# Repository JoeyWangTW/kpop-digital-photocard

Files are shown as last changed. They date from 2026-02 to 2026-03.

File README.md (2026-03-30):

# K-Pop Digital Photocard

A handheld device that plays K-pop YouTube Shorts as looping video "photocards" on a small display, powered by an ESP32-S3 with a 2.8" IPS screen.

<p align="center">
  Digital photocard playing video
  Back of 3D-printed case
  CO2 sensor mode
</p>

## Project Structure

```
kpop-digital-photocard/
├── firmware/          ESP32-S3 video player firmware (Arduino)
├── collection-app/    Streamlit app to browse, download & convert YouTube Shorts
├── case/              3D-printable enclosure (STL files)
└── docs/              Wiring diagrams, photos, BOM
```

## Hardware

### Parts List

| Part | Notes |
|---|---|
| [ESP32-S3 2.8" IPS Display (Hosyond)](https://amzn.to/4brwvC6) | ESP32-S3 with 320x240 ILI9341, SD card slot, PSRAM. Cheaper options available on AliExpress/Alibaba |
| MicroSD card | Any size works, FAT32 formatted |
| [Lipo Battery 1000mAh](https://amzn.to/40Pq1Xz) | JST connector, 3.7V |
| M3x12mm screws | For case assembly |
| [M3 Threaded inserts (M3xH4)](https://amzn.to/4lifAp9) | Heat-set with soldering iron into the 3D-printed case |

### 3D-Printed Case

STL files are in the `case/` folder:
- `front.stl` — Front shell with display cutout
- `back.stl` — Back cover
- `button.stl` — Boot button cap

Install the M3 threaded inserts into the case using a soldering iron, then secure with M3x12mm screws.

## Getting Started

### 1. Set Up the Collection App

The collection app is a Streamlit web app that lets you browse YouTube Shorts, download them, and convert to MJPEG format for the device.

**Prerequisites:**
- Python 3.12+
- [uv](https://docs.astral.sh/uv/) (Python package manager)
- FFmpeg

```bash
cd collection-app

# Install dependencies
uv sync

# Install FFmpeg if you haven't already
# macOS
brew install ffmpeg
# Ubuntu/Debian
sudo apt install ffmpeg

# Run the app
uv run streamlit run app.py
```

The app opens in your browser at `http://localhost:8501`.

### 2. Add Channels & Fetch Videos

1. In the sidebar, enter a YouTube channel URL, @handle, or channel ID
2. Click **Fetch All** or **Fetch New Videos** to pull the latest Shorts
3. Thumbnails and metadata are cached locally in `data/shorts.db`

### 3. Select & Download Videos

1. Browse the video grid and check the ones you want
2. Use bulk select to grab multiple videos at once
3. New videos (not previously seen) are highlighted

### 4. Convert to MJPEG

1. Adjust conversion settings in the sidebar:

   | Parameter | Default | Description |
   |-----------|---------|-------------|
   | Width | 240 | Output video width in pixels |
   | Height | 320 | Output video height in pixels |
   | Quality | 5 | MJPEG quality (2-31, lower = better) |
   | FPS | 15 | Frame rate |
   | Brightness | 0.05 | Brightness adjustment (-0.5 to 0.5) |
   | Contrast | 1.1 | Contrast adjustment (0.5 to 2.0) |
   | Aspect Mode | fit | How to handle aspect ratio (fit/fill/stretch) |

2. Presets are available for **CYD 2.8"** (240x320) and **CYD 4"** (320x480)
3. Click **Download & Convert** to process all selected videos

### 5. Prepare the SD Card

1. Format a microSD card as **FAT32**
2. Create a folder called `mjpeg` at the root of the SD card
3. Click **Export** in the app to copy converted `.mjpeg` files to a target folder, or manually copy from `collection-app/output/` to the SD card's `/mjpeg/` folder
4. The firmware reads FPS from the filename (e.g. `video_15fps.mjpeg`), otherwise defaults to 15 FPS

### 6. Flash the Firmware

The video player firmware is based on [esp32-2432S028_video_player](https://github.com/thelastoutpostworkshop/esp32-2432S028_video_player) by The Last Outpost Workshop, adapted for the ESP32-S3.

1. Install [Arduino IDE](https://www.arduino.cc/en/software)
2. Add ESP32 board support: in **Settings > Additional Board Manager URLs**, add:
   ```
   https://raw.githubusercontent.com/espressif/arduino-esp32/gh-pages/package_esp32_index.json
   ```
3. Install **esp32** board package from Board Manager
4. Install required libraries via Library Manager:
   - **TFT_eSPI**
   - **TJpg_Decoder**
5. Copy `firmware/User_Setup.h` to your TFT_eSPI library folder (replacing the default), or update the pin definitions to match
6. Open `firmware/esp32s3_video_player.ino` in Arduino IDE
7. Select board: **ESP32S3 Dev Module**
8. Board settings:
   - Flash Size: **16MB**
   - PSRAM: **OPI PSRAM**
   - USB CDC On Boot: **Enabled** (for serial monitor)
   - Partition Scheme: **Huge APP**
9. Connect the board via USB and click **Upload**

### 7. Usage

- Insert the SD card and power on the device
- Videos in `/mjpeg/` loop automatically
- **Short press** the boot button to skip to the next video
- **Long press** (1.5s) the boot button to enter deep sleep
- **Press** the boot button again to wake from sleep

## License

MIT

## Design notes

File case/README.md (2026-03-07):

# Case

3D-printable enclosure for the K-Pop Digital Photocard device.

## Parts

- `front.stl` — Front shell with display cutout
- `back.stl` — Back cover
- `button.stl` — Boot button cap

## Assembly

1. Print all three parts
2. Heat-set four M3x4mm threaded inserts into the front part using a soldering iron
3. Place the ESP32-S3 board into the front shell and snap in the button cap
4. Connect the lipo battery to the board
5. Use double-sided tape to secure the battery to the inside of the back cover
6. Place the back cover on and fasten with four M3x12mm screws

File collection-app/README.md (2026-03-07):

# CYD Shorts Converter

Fetch YouTube Shorts from channels and convert them to MJPEG format optimized for the CYD (Cheap Yellow Display) ESP32 device.

## Features

- Add YouTube channels by URL, @handle, or channel ID
- Fetch and display Shorts with thumbnails
- Track new vs previously seen videos
- Select videos individually or in bulk
- Download and convert to MJPEG format
- Adjustable conversion parameters (resolution, quality, FPS, brightness, contrast)
- Export to SD card or target folder
- Remembers selections between sessions

## Requirements

- Python 3.12+
- [uv](https://docs.astral.sh/uv/)
- FFmpeg

## Installation

1. Clone or download this repository

2. Install dependencies:
```bash
uv sync
```

3. Install FFmpeg:
```bash
# macOS
brew install ffmpeg

# Ubuntu/Debian
sudo apt install ffmpeg

# Windows
choco install ffmpeg
```

## Usage

Start the application:

```bash
uv run streamlit run app.py
```

The app will open in your browser at `http://localhost:8501`.

### Workflow

1. **Add Channels**: Enter a YouTube channel URL or @handle in the sidebar
2. **Fetch Videos**: Click "Fetch All" or "Fetch New Videos" to get Shorts
3. **Select Videos**: Check the videos you want to convert
4. **Adjust Settings**: Configure resolution, quality, and other parameters
5. **Convert**: Click "Download & Convert" to process selected videos
6. **Export**: Click "Export" to copy converted files to your target folder

### Settings

| Parameter | Default | Description |
|---|---|---|
| Width | 240 | Output video width in pixels |
| Height | 320 | Output video height in pixels |
| Quality | 5 | MJPEG quality (2-31, lower = better) |
| FPS | 15 | Frame rate |
| Brightness | 0.05 | Brightness adjustment (-0.5 to 0.5) |
| Contrast | 1.1 | Contrast adjustment (0.5 to 2.0) |
| Aspect Mode | fit | How to handle aspect ratio (fit/fill/stretch) |

### Presets

- **CYD 2.8"**: 240x320, optimized for the 2.8" display
- **CYD 4"**: 320x480, optimized for the 4" display

## Project Structure

```
digital-photocard-collection/
├── app.py                  # Streamlit application
├── pyproject.toml          # Project config and dependencies
├── src/
│   ├── models/            # Data classes
│   ├── services/          # Business logic
│   ├── components/        # Streamlit UI components
│   └── utils/             # Utilities
├── data/
│   ├── shorts.db          # SQLite database
│   ├── thumbnails/        # Cached thumbnails
│   └── downloads/         # Temporary downloads
└── output/                # Converted MJPEG files
```

## CYD Device

The CYD (Cheap Yellow Display) is the ESP32-2432S028R board with:
- ESP32-WROOM-32 MCU
- 2.8" ILI9341 TFT display (240x320 pixels)
- SD card slot for video storage

Copy the exported `.mjpeg` files to an SD card and use with a compatible MJPEG player firmware.

## License

MIT

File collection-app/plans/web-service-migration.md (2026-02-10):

# CYD Shorts Converter - Web Service Migration

## Overview

Migrate the CYD Shorts Converter from a local Streamlit app to a public-facing web service. Two product models are considered: an **ephemeral downloader** (paste URL, convert, download) and an **account-based service** (saved collections, user profiles). The ephemeral model is the recommended starting point.

## Why Move Off Streamlit

The current Streamlit app works well as a local tool but has hard blockers for a public service:

| Requirement | Streamlit Support |
|---|---|
| Ad injection (AdSense, etc.) | No HTML control -- impossible |
| User authentication | No native support |
| SEO / discoverability | Single-page app, not crawlable |
| Custom branding / design | Very limited theming |
| Concurrent users at scale | Expensive (full Python process per session) |
| Background job processing | Blocks the user session |
| URL routing | Not supported |
| File downloads to browser | Limited (`st.download_button` only) |

## What We Keep

The existing service layer is cleanly decoupled from Streamlit and is fully reusable:

| File | What It Does | Reusable? |
|---|---|---|
| `src/services/conversion_service.py` | FFmpeg MJPEG pipeline | Yes -- no Streamlit dependency |
| `src/services/download_service.py` | yt-dlp video download | Yes -- no Streamlit dependency |
| `src/services/youtube_service.py` | Channel/video metadata fetching | Yes -- no Streamlit dependency |
| `src/models/` | Data classes (Video, Channel, Settings) | Yes -- plain Python dataclasses |
| `src/utils/ffmpeg_utils.py` | FFmpeg detection and helpers | Yes |
| `src/services/database.py` | SQLite persistence | Needs rework for multi-user |
| `src/components/` | Streamlit UI components | No -- replaced entirely |

## Product Model Decision

### Option A: Ephemeral Downloader (Recommended Start)

Users land on the site, paste a YouTube URL (or browse channels), pick conversion settings, and download the `.mjpeg` file. No account required. Monetize with ads.

**Pros:**
- Simplest to build and ship
- No auth, no user storage, no ongoing data responsibility
- Easy to monetize with display ads
- Low infrastructure cost (temp files auto-cleaned)
- Good for SEO ("youtube to mjpeg converter", "CYD video converter")

**Cons:**
- No user retention / return visits without new features
- Can't save collections or history
- Harder to build a community around

### Option B: Account-Based Service

Users create accounts, save channels, maintain collections, track conversion history.

**Pros:**
- User retention and repeat visits
- Can build community features (share collections, popular channels)
- Subscription potential (free tier with limits, paid for more)

**Cons:**
- Significantly more infrastructure (auth, user DB, file storage)
- Data responsibility (GDPR, user data management)
- Higher hosting costs (persistent storage per user)
- Longer time to ship

### Recommendation

**Start with Option A**, then layer on accounts (Option B) once there's traction. The backend architecture supports both -- adding auth and user-scoped storage later is straightforward.

---

## Technical Architecture

### Option A: Ephemeral Downloader

```
                    ┌─────────────────────────────────────┐
                    │         Frontend (Next.js)           │
                    │  ┌───────────────────────────────┐   │
                    │  │  Landing page (SEO-optimized) │   │
                    │  │  URL input + settings form    │   │
                    │  │  Progress polling UI           │   │
                    │  │  Download button               │   │
                    │  │  Ad placements (sidebar, top)  │   │
                    │  └───────────────────────────────┘   │
                    └──────────────┬──────────────────────┘
                                   │ REST API
                    ┌──────────────▼──────────────────────┐
                    │         Backend (FastAPI)            │
                    │  POST /api/convert                   │
                    │  GET  /api/status/{job_id}           │
                    │  GET  /api/download/{job_id}         │
                    │  GET  /api/presets                   │
                    └──────────────┬──────────────────────┘
                                   │ Task queue
                    ┌──────────────▼──────────────────────┐
                    │     Worker (Celery or arq)           │
                    │  ┌─────────────────────────────┐     │
                    │  │  download_service.py (reuse) │     │
                    │  │  conversion_service.py (reuse│)    │
                    │  └─────────────────────────────┘     │
                    │           │                │          │
                    │     yt-dlp download    FFmpeg convert │
                    └──────────────┬──────────────────────┘
                                   │
                    ┌──────────────▼──────────────────────┐
                    │         Storage                      │
                    │  Redis: job queue + status cache      │
                    │  /tmp/jobs/{job_id}/: temp files      │
                    │  Cron: cleanup files > 1 hour old     │
                    └──────────────────────────────────────┘
```

### Option B: Account-Based (future layer)

Adds on top of Option A:

```
                    ┌──────────────────────────────────────┐
                    │  Auth Provider (Clerk / Supabase)     │
                    └──────────────┬───────────────────────┘
                                   │
                    ┌──────────────▼───────────────────────┐
                    │  PostgreSQL                           │
                    │  ├── users (id, email, plan)          │
                    │  ├── collections (user_id, name)      │
                    │  ├── collection_items (video_id, ...)  │
                    │  └── conversion_history                │
                    └──────────────────────────────────────┘
                                   │
                    ┌──────────────▼───────────────────────┐
                    │  S3 / R2 (persistent file storage)   │
                    │  /{user_id}/{video_id}.mjpeg          │
                    └──────────────────────────────────────┘
```

---

## API Design (Option A)

### POST /api/convert

Start a conversion job.

```json
// Request
{
  "url": "https://www.youtube.com/shorts/abc123",
  "settings": {
    "width": 240,
    "height": 320,
    "quality": 5,
    "fps": 15,
    "brightness": 0.05,
    "contrast": 1.1,
    "aspect_mode": "fit"
  }
}

// Response
{
  "job_id": "uuid-here",
  "status": "queued",
  "estimated_seconds": 30
}
```

### GET /api/status/{job_id}

Poll job progress.

```json
// Response
{
  "job_id": "uuid-here",
  "status": "converting",     // queued | downloading | converting | done | error
  "progress": 65.5,
  "stage": "converting",
  "video_title": "Some Cool Short",
  "thumbnail_url": "https://i.ytimg.com/vi/abc123/hqdefault.jpg"
}
```

### GET /api/download/{job_id}

Download the converted file. Returns the `.mjpeg` file as a binary download.

Headers: `Content-Disposition: attachment; filename="video-title.mjpeg"`

### GET /api/presets

Return available device presets.

```json
{
  "presets": [
    { "name": "CYD 2.8\"", "width": 240, "height": 320, "quality": 5, "fps": 15 },
    { "name": "CYD 4\"", "width": 320, "height": 480, "quality": 5, "fps": 15 }
  ]
}
```

---

## Tech Stack

### Frontend

| Choice | Why |
|---|---|
| **Next.js** (React) | SSR for SEO, file-based routing, easy deployment on Vercel |
| **Tailwind CSS** | Fast styling, responsive design |
| **shadcn/ui** | Clean component library, easy to customize |

Alternatives considered:
- Plain HTML + HTMX: Simpler but harder to do rich progress UI and ad integration
- Astro: Good for static content but less natural for the interactive conversion flow

### Backend

| Choice | Why |
|---|---|
| **FastAPI** | Python (reuse existing services), async, auto-generated API docs |
| **Celery + Redis** | Background task queue for download/conversion jobs |
| **Redis** | Job status caching, rate limiting |

Alternatives considered:
- arq (lighter than Celery): Good for smaller scale, easier setup
- Django: More batteries but heavier than needed for an API

### Infrastructure

| Choice | Why |
|---|---|
| **VPS (Hetzner/DigitalOcean)** | Need CPU for FFmpeg, full control over system deps |
| **Docker Compose** | Single-command deployment of all services |
| **Caddy or nginx** | Reverse proxy, auto-SSL |
| **Cron cleanup job** | Delete temp files older than 1 hour |

**Not suitable:** Vercel/Netlify serverless (need long-running FFmpeg processes, system-level deps)

Frontend can still be on Vercel, calling the backend API on the VPS.

---

## Frontend Pages

### Landing / Converter Page (`/`)

The main page. SEO-optimized for "YouTube to MJPEG converter", "CYD video converter".

```
┌──────────────────────────────────────────────────────────────────┐
│  [Ad banner]                                                      │
├──────────────────────────────────────────────────────────────────┤
│                                                                    │
│  CYD Shorts Converter                                              │
│  Convert YouTube Shorts to MJPEG for your CYD display              │
│                                                                    │
│  ┌──────────────────────────────────────────────────────────┐      │
│  │  Paste YouTube URL here...                        [Go]   │      │
│  └──────────────────────────────────────────────────────────┘      │
│                                                                    │
│  Preset: [CYD 2.8"] [CYD 4"] [Custom]                             │
│                                                                    │
│  ┌─ Advanced Settings (collapsed) ──────────────────────────┐      │
│  │  Width: [240]  Height: [320]  Quality: [5]  FPS: [15]    │      │
│  │  Brightness: [0.05]  Contrast: [1.1]  Aspect: [Fit]      │      │
│  └──────────────────────────────────────────────────────────┘      │
│                                                                    │
│  ── Progress ────────────────────────────────────────────────      │
│  ┌──────────┐                                                      │
│  │ [thumb]  │  "Dance Tutorial #shorts"                            │
│  │          │  ████████████████░░░░░░  Converting... 72%           │
│  └──────────┘                                                      │
│                                                                    │
│  [Download .mjpeg]  (appears when done)                            │
│                                                                    │
├──────────────────────────────────────────────────────────────────┤
│  [Ad sidebar / bottom]                                             │
├──────────────────────────────────────────────────────────────────┤
│  What is CYD?  │  How to use  │  FAQ  │  GitHub                   │
│  (SEO content blocks)                                              │
└──────────────────────────────────────────────────────────────────┘
```

### About / How-To Page (`/about`)

Static content explaining CYD, the conversion process, compatible devices. Good for SEO.

---

## Implementation Phases

### Phase 1: FastAPI Backend (wrap existing services)

**Goal:** API that accepts a YouTube URL and returns a converted `.mjpeg` file.

**Tasks:**
- [ ] Set up FastAPI project structure
- [ ] Create job model and Redis-backed status store
- [ ] Wire up `POST /api/convert` endpoint
- [ ] Integrate existing `DownloadService` and `ConversionService` into Celery worker
- [ ] Implement `GET /api/status/{job_id}` with progress polling
- [ ] Implement `GET /api/download/{job_id}` with file streaming
- [ ] Add `GET /api/presets` endpoint
- [ ] Add rate limiting (3 jobs per hour per IP)
- [ ] Add temp file cleanup (cron or background task)
- [ ] Dockerfile for backend + worker + Redis

**Success criteria:**
- `curl -X POST /api/convert` with a YouTube URL → returns job_id
- Poll status until done → download working `.mjpeg` file
- Files auto-cleaned after 1 hour

### Phase 2: Frontend (Next.js)

**Goal:** Clean, ad-ready landing page with conversion UI.

**Tasks:**
- [ ] Next.js project with Tailwind + shadcn/ui
- [ ] Landing page with URL input and preset selector
- [ ] Advanced settings panel (collapsible)
- [ ] Job progress UI with polling
- [ ] Download button (triggers browser file download)
- [ ] SEO: meta tags, Open Graph, structured data
- [ ] Static content blocks (What is CYD, How to use, FAQ)
- [ ] Mobile responsive layout
- [ ] Ad placement zones (header, sidebar, between content)
- [ ] Error states (invalid URL, conversion failed, rate limited)

**Success criteria:**
- User can paste URL, click Go, wait for progress, download file
- Page loads fast, looks professional
- Works on mobile
- Ad zones render correctly

### Phase 3: Deployment & Infrastructure

**Goal:** Live on the internet, accessible to anyone.

**Tasks:**
- [ ] Docker Compose for backend (FastAPI + Celery + Redis)
- [ ] Deploy backend to VPS (Hetzner or DigitalOcean)
- [ ] Deploy frontend to Vercel (or same VPS behind nginx)
- [ ] Set up domain and SSL
- [ ] Set up Google AdSense (or alternative ad network)
- [ ] Basic monitoring (uptime, error rates)
- [ ] Log aggregation for debugging

**Success criteria:**
- App accessible at chosen domain
- End-to-end flow works publicly
- Ads rendering and generating impressions

### Phase 4: Hardening & Growth (post-launch)

**Tasks:**
- [ ] Analytics (Plausible or PostHog)
- [ ] Abuse prevention (block massive automated usage)
- [ ] Video length / size limits
- [ ] Queue depth management (reject jobs when too busy)
- [ ] Error tracking (Sentry)
- [ ] Social sharing (Open Graph previews)
- [ ] Batch conversion (paste multiple URLs)

### Phase 5: Accounts (Option B, if traction warrants it)

**Tasks:**
- [ ] Add auth provider (Clerk or Supabase Auth)
- [ ] PostgreSQL for user data
- [ ] User dashboard (conversion history, saved presets)
- [ ] Saved collections (bookmarked channels/videos)
- [ ] S3/R2 for persistent file storage
- [ ] Free vs paid tiers (rate limits, priority queue, no ads)

---

## Cost Estimates

### Ephemeral Downloader (Option A)

| Item | Monthly Cost |
|---|---|
| VPS (4 vCPU, 8GB RAM -- Hetzner CX31) | ~$15 |
| Domain | ~$1 |
| Vercel (frontend, free tier) | $0 |
| Redis (on same VPS) | $0 |
| Bandwidth (1TB included on Hetzner) | $0 |
| **Total** | **~$16/month** |

Can handle ~50-100 conversions/day on this setup. Scale by adding worker VPS nodes.

### Account-Based (Option B addition)

| Item | Additional Cost |
|---|---|
| Managed PostgreSQL (or self-host on VPS) | $0-15 |
| S3/R2 storage (Cloudflare R2 has free egress) | $0-5 |
| Auth provider (Clerk free tier) | $0 |
| **Additional total** | **~$0-20/month** |

---

## Revenue Considerations

### Ad Revenue (Option A)

- Display ads (Google AdSense): ~$1-5 RPM (revenue per 1000 page views)
- At 1000 conversions/day with ~3 page views each = 3000 views/day = 90K/month
- Estimated: **$90-450/month** at scale
- Niche audience (CYD/ESP32 hobbyists) may have higher RPM due to tech/maker demographic

### Subscription (Option B)

- Free tier: 3 conversions/day, ads shown
- Pro tier ($5/month): unlimited conversions, no ads, saved collections, priority queue
- Even 50 paying users = $250/month

---

## Risk Analysis

| Risk | Likelihood | Impact | Mitigation |
|---|---|---|---|
| YouTube/yt-dlp breakage | Medium | High | Pin yt-dlp version, monitor releases, quick update pipeline |
| High server CPU from FFmpeg | High | Medium | Rate limiting, job queue depth limits, horizontal scaling |
| Abuse (bot traffic, excessive usage) | Medium | Medium | Rate limiting per IP, CAPTCHA on excessive use |
| Low traffic / no traction | Medium | Medium | Low cost base (~$16/mo), easy to sunset |
| DMCA / copyright concerns | Low | High | Only convert user-requested public videos, don't host/cache content |
| yt-dlp TOS concerns | Medium | Medium | App converts format for personal device use, similar to other converter sites |

---

## Migration Path from Current App

The Streamlit app continues to work as-is for local/personal use. The web service is a separate deployment that reuses the core services:

```
digital-photocard-collection/
├── app.py                          # Keep -- local Streamlit app still works
├── src/
│   ├── services/                   # Shared -- used by both Streamlit and FastAPI
│   │   ├── conversion_service.py
│   │   ├── download_service.py
│   │   └── youtube_service.py
│   ├── models/                     # Shared
│   └── components/                 # Streamlit only (stays for local use)
│
├── web/                            # NEW -- web service
│   ├── api/                        # FastAPI backend
│   │   ├── main.py
│   │   ├── routes/
│   │   │   └── convert.py
│   │   ├── worker.py               # Celery worker
│   │   ├── jobs.py                 # Job management
│   │   └── Dockerfile
│   ├── frontend/                   # Next.js frontend
│   │   ├── app/
│   │   │   ├── page.tsx            # Landing / converter
│   │   │   └── about/page.tsx
│   │   ├── components/
│   │   ├── package.json
│   │   └── Dockerfile
│   └── docker-compose.yml          # Full stack deployment
│
├── plans/
│   ├── youtube-shorts-mjpeg-converter.md   # Original plan
│   └── web-service-migration.md            # This document
└── requirements.txt
```

The key insight: **`src/services/` is the shared core**. Both the local Streamlit app and the web service import from it. No code duplication.

---

*Generated with Claude Code*

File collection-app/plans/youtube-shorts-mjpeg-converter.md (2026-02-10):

# YouTube Shorts MJPEG Converter for CYD

## Overview

Build a Python desktop application that fetches YouTube Shorts from specified channels, provides a UI for video selection, and converts selected videos to MJPEG format optimized for the CYD (Cheap Yellow Display) ESP32 device with a 240x320 TFT screen.

## Problem Statement / Motivation

The CYD (Cheap Yellow Display - ESP32-2432S028R) is a popular ~$15 ESP32 board with a 2.8" TFT display (240x320 pixels). To display video content, videos must be converted to MJPEG format with specific parameters. Currently, this requires:

1. Manually finding and copying YouTube Shorts URLs
2. Running command-line tools to download and convert
3. Manually tracking which videos have been processed
4. Re-downloading everything when new content is available

This application automates the workflow with a visual interface for browsing, selecting, and converting Shorts for CYD playback.

## Proposed Solution

A **Python desktop application** using:
- **CustomTkinter** for native desktop UI (based on "not web-based preferred" requirement)
- **SQLite** for data persistence and state tracking
- **yt-dlp** for video downloading (bypasses API quota issues)
- **FFmpeg** for MJPEG conversion
- **YouTube Data API v3** (optional) for enhanced metadata

### Architecture Decision: Desktop vs Web

| Approach | Pros | Cons |
|---|---|---|
| **Web (Streamlit)** | Rapid development, easy thumbnails/grids, video preview, cross-platform | Requires browser |
| **Desktop (CustomTkinter)** | Native feel, no browser needed | Complex image grids, more boilerplate |

**Recommendation: Streamlit** - For an application focused on browsing and selecting videos with thumbnails, web UI is natural and less clunky. Streamlit runs locally (`localhost:8501`) and provides an excellent developer experience with minimal code.

## Technical Approach

### System Architecture

```
┌─────────────────────────────────────────────────────────────────┐
│                    CYD Shorts Converter                         │
├─────────────────────────────────────────────────────────────────┤
│  UI Layer (Streamlit @ localhost:8501)                          │
│  ├── Sidebar: Channel Manager + Settings                        │
│  ├── Main: Video Grid with thumbnails and checkboxes            │
│  ├── Progress bars for download/conversion                      │
│  └── Session state for selections                               │
├─────────────────────────────────────────────────────────────────┤
│  Service Layer                                                  │
│  ├── YouTubeService (fetch channel videos via yt-dlp)           │
│  ├── DownloadService (download with progress)                   │
│  ├── ConversionService (FFmpeg MJPEG encoding)                  │
│  └── ExportService (copy to target folder)                      │
├─────────────────────────────────────────────────────────────────┤
│  Data Layer (SQLite)                                            │
│  ├── channels (id, name, url, last_fetched)                     │
│  ├── videos (id, channel_id, title, duration, is_short, ...)    │
│  ├── video_state (video_id, selected, downloaded, converted)    │
│  └── settings (key, value)                                      │
└─────────────────────────────────────────────────────────────────┘
```

### Data Flow

```
User adds channel URL
        │
        ▼
yt-dlp extracts video list (no API key needed)
        │
        ▼
Filter for Shorts (duration ≤ 60s, vertical aspect ratio)
        │
        ▼
Store metadata in SQLite, mark as "new" if not exists
        │
        ▼
UI displays videos with thumbnails
        │
        ▼
User selects/deselects videos
        │
        ▼
User clicks "Convert" → Download selected → Convert to MJPEG
        │
        ▼
User clicks "Export" → Copy MJPEG files to target folder
```

### Database Schema

```sql
-- schema.sql

CREATE TABLE IF NOT EXISTS channels (
    id TEXT PRIMARY KEY,           -- YouTube channel ID (UCxxxxx)
    name TEXT NOT NULL,            -- Channel display name
    url TEXT NOT NULL,             -- Original URL provided by user
    last_fetched TIMESTAMP,        -- Last time videos were fetched
    created_at TIMESTAMP DEFAULT CURRENT_TIMESTAMP
);

CREATE TABLE IF NOT EXISTS videos (
    id TEXT PRIMARY KEY,           -- YouTube video ID
    channel_id TEXT NOT NULL,      -- References channels.id
    title TEXT NOT NULL,
    description TEXT,
    thumbnail_url TEXT,
    duration INTEGER NOT NULL,     -- Duration in seconds
    published_at TIMESTAMP,
    width INTEGER,                 -- Original video width
    height INTEGER,                -- Original video height
    is_short BOOLEAN DEFAULT 0,   -- Detected as Short
    created_at TIMESTAMP DEFAULT CURRENT_TIMESTAMP,
    FOREIGN KEY (channel_id) REFERENCES channels(id)
);

CREATE TABLE IF NOT EXISTS video_state (
    video_id TEXT PRIMARY KEY,
    is_new BOOLEAN DEFAULT 1,      -- First time seen
    is_selected BOOLEAN DEFAULT 0, -- User selected for conversion
    is_downloaded BOOLEAN DEFAULT 0,
    is_converted BOOLEAN DEFAULT 0,
    is_exported BOOLEAN DEFAULT 0,
    download_path TEXT,            -- Path to downloaded source
    converted_path TEXT,           -- Path to MJPEG file
    conversion_settings TEXT,      -- JSON of settings used
    seen_at TIMESTAMP,             -- When user first saw this
    downloaded_at TIMESTAMP,
    converted_at TIMESTAMP,
    exported_at TIMESTAMP,
    FOREIGN KEY (video_id) REFERENCES videos(id)
);

CREATE TABLE IF NOT EXISTS settings (
    key TEXT PRIMARY KEY,
    value TEXT NOT NULL
);

-- Indexes for performance
CREATE INDEX IF NOT EXISTS idx_videos_channel ON videos(channel_id);
CREATE INDEX IF NOT EXISTS idx_videos_is_short ON videos(is_short);
CREATE INDEX IF NOT EXISTS idx_state_is_new ON video_state(is_new);
CREATE INDEX IF NOT EXISTS idx_state_is_selected ON video_state(is_selected);
```

### Key Implementation Details

#### Shorts Detection (via yt-dlp)

```python
# services/youtube_service.py

def is_youtube_short(video_info: dict) -> bool:
    """Determine if a video is a YouTube Short."""
    duration = video_info.get('duration', 0)
    width = video_info.get('width', 0)
    height = video_info.get('height', 0)

    # Shorts are ≤60 seconds and vertical (9:16 aspect ratio)
    is_short_duration = duration <= 60
    is_vertical = height > width if (width and height) else False

    # Also check for #shorts in title or description
    text = f"{video_info.get('title', '')} {video_info.get('description', '')}".lower()
    has_shorts_tag = '#shorts' in text or '#short' in text

    return is_short_duration and (is_vertical or has_shorts_tag)
```

#### MJPEG Conversion Settings

```python
# services/conversion_service.py

@dataclass
class ConversionConfig:
    width: int = 240              # CYD display width
    height: int = 320             # CYD display height
    quality: int = 5              # MJPEG quality (2-31, lower=better)
    fps: int = 15                 # Frame rate
    brightness: float = 0.05     # Slight boost for small display
    contrast: float = 1.1         # Slight boost for visibility
    aspect_mode: str = "fit"      # fit (letterbox), fill (crop), stretch

def build_ffmpeg_command(input_path: str, output_path: str,
                         config: ConversionConfig) -> list:
    """Build FFmpeg command for MJPEG conversion."""
    filters = []

    if config.aspect_mode == "fit":
        # Letterbox: maintain aspect ratio, add black bars
        filters.append(
            f"scale={config.width}:{config.height}:"
            f"force_original_aspect_ratio=decrease"
        )
        filters.append(
            f"pad={config.width}:{config.height}:(ow-iw)/2:(oh-ih)/2"
        )
    elif config.aspect_mode == "fill":
        # Crop to fill entire frame
        filters.append(
            f"scale={config.width}:{config.height}:"
            f"force_original_aspect_ratio=increase"
        )
        filters.append(
            f"crop={config.width}:{config.height}"
        )
    else:  # stretch
        filters.append(f"scale={config.width}:{config.height}")

    # Add brightness/contrast adjustment
    filters.append(
        f"eq=brightness={config.brightness}:contrast={config.contrast}"
    )

    return [
        'ffmpeg', '-y',
        '-i', input_path,
        '-vf', ','.join(filters),
        '-c:v', 'mjpeg',
        '-q:v', str(config.quality),
        '-r', str(config.fps),
        '-pix_fmt', 'yuvj420p',
        '-an',  # No audio
        output_path
    ]
```

#### Progress Tracking

```python
# services/download_service.py

class DownloadProgress:
    """Track download progress for UI updates."""

    def __init__(self, callback: Callable[[str, float, str], None]):
        self.callback = callback  # (video_id, percent, status)

    def hook(self, d: dict):
        if d['status'] == 'downloading':
            total = d.get('total_bytes') or d.get('total_bytes_estimate', 0)
            downloaded = d.get('downloaded_bytes', 0)
            percent = (downloaded / total * 100) if total > 0 else 0
            self.callback(d.get('info_dict', {}).get('id'), percent, 'downloading')
        elif d['status'] == 'finished':
            self.callback(d.get('info_dict', {}).get('id'), 100, 'downloaded')
```

### File Structure

```
digital-photocard-collection/
├── app.py                      # Streamlit app entry (streamlit run app.py)
├── requirements.txt            # Python dependencies
├── config.yaml                 # User configuration
├── src/
│   ├── __init__.py
│   ├── models/
│   │   ├── __init__.py
│   │   ├── channel.py          # Channel dataclass
│   │   ├── video.py            # Video dataclass
│   │   └── settings.py         # Settings dataclass
│   ├── services/
│   │   ├── __init__.py
│   │   ├── database.py         # SQLite operations
│   │   ├── youtube_service.py  # yt-dlp wrapper for fetching
│   │   ├── download_service.py # Video downloading
│   │   ├── conversion_service.py # FFmpeg MJPEG conversion
│   │   └── export_service.py   # Copy to target folder
│   ├── components/
│   │   ├── __init__.py
│   │   ├── channel_sidebar.py  # Streamlit sidebar for channels
│   │   ├── video_grid.py       # Video thumbnail grid component
│   │   ├── settings_panel.py   # Conversion settings sliders
│   │   └── progress_display.py # Progress bars and status
│   └── utils/
│       ├── __init__.py
│       ├── ffmpeg_utils.py     # FFmpeg detection and commands
│       └── thumbnail_cache.py  # Local thumbnail caching
├── data/
│   ├── shorts.db               # SQLite database
│   ├── thumbnails/             # Cached thumbnail images
│   └── downloads/              # Temporary downloaded videos
├── output/                     # Converted MJPEG files
└── plans/
    └── youtube-shorts-mjpeg-converter.md
```

### UI Layout (Streamlit)

```
┌─────────────────────────────────────────────────────────────────────────┐
│  🎬 CYD Shorts Converter                              localhost:8501   │
├───────────────────────┬─────────────────────────────────────────────────┤
│  SIDEBAR              │  MAIN CONTENT                                   │
│                       │                                                 │
│  📺 Channels          │  Filter: [All Channels ▼]  [☑ New Only]         │
│  ┌─────────────────┐  │  Selected: 15/47 │ New: 17 │ Converted: 30      │
│  │ + Add Channel   │  │  ─────────────────────────────────────────────  │
│  └─────────────────┘  │                                                 │
│                       │  ┌──────────┐ ┌──────────┐ ┌──────────┐         │
│  ☑ @Channel1 (12)     │  │  [IMG]   │ │  [IMG]   │ │  [IMG]   │         │
│  ☑ @Channel2 (5)      │  │ Title 1  │ │ Title 2  │ │ Title 3  │         │
│  ☐ @Channel3 (0)      │  │ 0:45 NEW │ │ 0:32     │ │ 0:58 NEW │         │
│                       │  │ [☑]      │ │ [☑]      │ │ [☐]      │         │
│  [🔄 Fetch All]       │  └──────────┘ └──────────┘ └──────────┘         │
│                       │                                                 │
│  ─────────────────    │  ┌──────────┐ ┌──────────┐ ┌──────────┐         │
│                       │  │  [IMG]   │ │  [IMG]   │ │  [IMG]   │         │
│  ⚙️ Settings          │  │ Title 4  │ │ Title 5  │ │ Title 6  │         │
│                       │  │ 0:28 ✓   │ │ 0:55     │ │ 0:41     │         │
│  Resolution           │  │ [☑]      │ │ [☐]      │ │ [☑]      │         │
│  [240] x [320]        │  └──────────┘ └──────────┘ └──────────┘         │
│                       │                                                 │
│  Quality: [5]         │  [Select All] [Deselect All] [Invert]           │
│  ▬▬▬▬●▬▬▬▬▬▬          │                                                 │
│                       │  ─────────────────────────────────────────────  │
│  FPS: [15]            │                                                 │
│  ▬▬▬▬▬●▬▬▬▬▬          │  📥 Download & Convert                          │
│                       │  ┌─────────────────────────────────────────┐    │
│  Brightness: [0.05]   │  │ ████████████░░░░░░░░  12/15 Converting  │    │
│  ▬▬▬▬▬●▬▬▬▬▬          │  └─────────────────────────────────────────┘    │
│                       │                                                 │
│  Aspect: [Fit ▼]      │  📤 Export to: /Volumes/SD/mjpeg                │
│                       │  [Browse...] [Export Selected]                  │
│  ─────────────────    │                                                 │
│  📁 Export Path       │                                                 │
│  /Volumes/SD/mjpeg    │                                                 │
└───────────────────────┴─────────────────────────────────────────────────┘
```

**Streamlit Component Mapping:**
- `st.sidebar` → Channel list + Settings
- `st.columns(3)` → Video thumbnail grid
- `st.image()` → Thumbnails from cache or URL
- `st.checkbox()` → Video selection
- `st.progress()` → Download/conversion progress
- `st.session_state` → Persist selections across reruns

## Implementation Phases

### Phase 1: Core Infrastructure

**Tasks:**
- [ ] Set up project structure (`app.py`, `src/`, `data/`)
- [ ] Implement SQLite database layer (`src/services/database.py`)
- [ ] Create data models (`src/models/`)
- [ ] Implement YouTube service using yt-dlp (`src/services/youtube_service.py`)
- [ ] Add Shorts detection logic (duration + aspect ratio)
- [ ] Create basic CLI for testing core functionality

**Success Criteria:**
- Can add a channel URL and fetch video list
- Correctly identifies Shorts vs regular videos
- Persists video metadata to SQLite

### Phase 2: Download & Conversion Pipeline

**Tasks:**
- [ ] Implement download service with progress hooks (`src/services/download_service.py`)
- [ ] Create FFmpeg conversion wrapper (`src/services/conversion_service.py`)
- [ ] Add conversion parameter configuration
- [ ] Implement "new video" detection on re-fetch
- [ ] Add source video cleanup after conversion
- [ ] Create thumbnail caching system (`src/utils/thumbnail_cache.py`)

**Success Criteria:**
- Can download and convert a video to MJPEG
- Conversion respects all parameters (size, quality, fps, brightness)
- Thumbnails are cached locally for offline viewing
- Re-fetching only marks genuinely new videos

### Phase 3: Streamlit UI

**Tasks:**
- [ ] Set up Streamlit app structure (`app.py`)
- [ ] Create sidebar with channel management (`src/components/channel_sidebar.py`)
- [ ] Build video thumbnail grid with selection (`src/components/video_grid.py`)
- [ ] Add settings panel with sliders (`src/components/settings_panel.py`)
- [ ] Implement progress display for batch operations (`src/components/progress_display.py`)
- [ ] Use `st.session_state` for persistent selections
- [ ] Add filtering (by channel, new only, selected only)

**Success Criteria:**
- Functional UI matching the layout design
- Can add channels, browse videos, select/deselect
- Visual distinction between new, selected, and converted videos
- Real-time progress feedback during operations
- Responsive grid layout for thumbnails

### Phase 4: Export & Polish

**Tasks:**
- [ ] Implement export service (`src/services/export_service.py`)
- [ ] Add file naming strategy (channel_videoid.mjpeg)
- [ ] Create settings persistence (config.yaml)
- [ ] Add dependency detection (FFmpeg, yt-dlp) with install guidance
- [ ] Implement error handling with user-friendly messages
- [ ] Add logging for debugging
- [ ] Create README with usage instructions

**Success Criteria:**
- Can export converted videos to SD card folder
- Settings persist between sessions
- Clear error messages when dependencies are missing
- Application is ready for daily use

## Acceptance Criteria

### Functional Requirements

- [ ] Add YouTube channels by URL, handle, or ID
- [ ] Fetch and display Shorts from added channels
- [ ] Distinguish between new and previously seen videos
- [ ] Select/deselect videos individually or in bulk
- [ ] Remember selections between sessions
- [ ] Download selected videos with progress indication
- [ ] Convert to MJPEG with configurable parameters:
  - [ ] Width and height (default 240x320)
  - [ ] Quality (1-31 scale)
  - [ ] Frame rate (1-30 fps)
  - [ ] Brightness (-1.0 to 1.0)
  - [ ] Contrast (0.5 to 2.0)
  - [ ] Aspect mode (fit/fill/stretch)
- [ ] Export converted files to user-specified folder
- [ ] Only download new videos on subsequent fetches
- [ ] Only convert videos that haven't been converted (or settings changed)

### Non-Functional Requirements

- [ ] UI remains responsive during download/conversion (threaded operations)
- [ ] Works offline for browsing cached data
- [ ] Handles network errors gracefully with retry option
- [ ] Detects and reports missing FFmpeg/yt-dlp
- [ ] Database migrations for future schema changes

### Quality Gates

- [ ] All core services have error handling
- [ ] UI tested with 100+ videos from 5+ channels
- [ ] Converted videos play correctly on CYD device
- [ ] Memory usage stable during batch processing
- [ ] Clean shutdown with no orphaned processes

## Success Metrics

1. **Workflow efficiency**: Reduce manual steps from ~10 to ~3 clicks per batch
2. **Reliability**: 95%+ of Shorts successfully converted
3. **Usability**: New user can add channel and convert first video in <2 minutes
4. **Performance**: Process 50 Shorts in <10 minutes on typical hardware

## Dependencies & Prerequisites

### Required
- Python 3.10+
- FFmpeg (system install)
- yt-dlp (`pip install yt-dlp`)
- Streamlit (`pip install streamlit`)
- Pillow for image handling (`pip install pillow`)

### Optional
- YouTube Data API key (for enhanced metadata, quota-sensitive)

### System Requirements
- 500MB disk space for application and cache
- Internet connection for fetching videos
- SD card reader for CYD export (or network-accessible folder)

## Risk Analysis & Mitigation

| Risk | Likelihood | Impact | Mitigation |
|---|---|---|---|
| yt-dlp breaks with YouTube updates | Medium | High | Pin version, monitor releases, fallback to API |
| FFmpeg not installed on user system | Medium | High | Detect at startup, provide installation guide |
| API quota exceeded | Low | Medium | Use yt-dlp instead of API for video list |
| Large video count overwhelms UI | Medium | Medium | Implement pagination/virtual scrolling |
| Conversion fails for some videos | Low | Low | Log errors, allow retry, skip problematic files |

## Future Considerations

- **Playlist support**: Allow importing from YouTube playlists
- **Scheduled fetching**: Auto-check for new videos on interval
- **Preview in app**: Play video thumbnail preview before downloading
- **Batch settings**: Apply different settings to different channels
- **Direct CYD transfer**: WiFi upload to CYD's built-in web server
- **Multiple display profiles**: Presets for different CYD display sizes

## References & Research

### Internal References
- Existing conversion script: `/Users/joeywang/Documents/Maker/CYD/ive/download_and_convert.py`
- CYD video player firmware: `/Users/joeywang/Documents/Maker/CYD/esp32-2432S028_video_player/`
- MJPEG decoder class: `/Users/joeywang/Documents/Maker/CYD/CYD-photocard-display/MjpegClass.h`

### External References
- [yt-dlp Documentation](https://github.com/yt-dlp/yt-dlp)
- [FFmpeg MJPEG Encoding](https://ffmpeg.org/ffmpeg-codecs.html#mjpeg)
- [Streamlit Documentation](https://docs.streamlit.io/)
- [YouTube Data API v3](https://developers.google.com/youtube/v3/docs)
- [CYD (ESP32-2432S028R) Info](https://github.com/witnessmenow/ESP32-Cheap-Yellow-Display)

### Related Work
- Existing URL list approach: `/Users/joeywang/Documents/Maker/CYD/ive/video.txt`
- WiFi upload feature in CYD-photocard-display project

---

## ERD Diagram

```mermaid
erDiagram
    channels ||--o{ videos : "has many"
    videos ||--|| video_state : "has one"

    channels {
        text id PK "YouTube channel ID"
        text name "Channel display name"
        text url "Original URL"
        timestamp last_fetched
        timestamp created_at
    }

    videos {
        text id PK "YouTube video ID"
        text channel_id FK "References channels.id"
        text title
        text description
        text thumbnail_url
        integer duration "Duration in seconds"
        timestamp published_at
        integer width
        integer height
        boolean is_short
        timestamp created_at
    }

    video_state {
        text video_id PK FK "References videos.id"
        boolean is_new
        boolean is_selected
        boolean is_downloaded
        boolean is_converted
        boolean is_exported
        text download_path
        text converted_path
        text conversion_settings "JSON"
        timestamp seen_at
        timestamp downloaded_at
        timestamp converted_at
        timestamp exported_at
    }

    settings {
        text key PK
        text value
    }
```

---

*Generated with Claude Code*

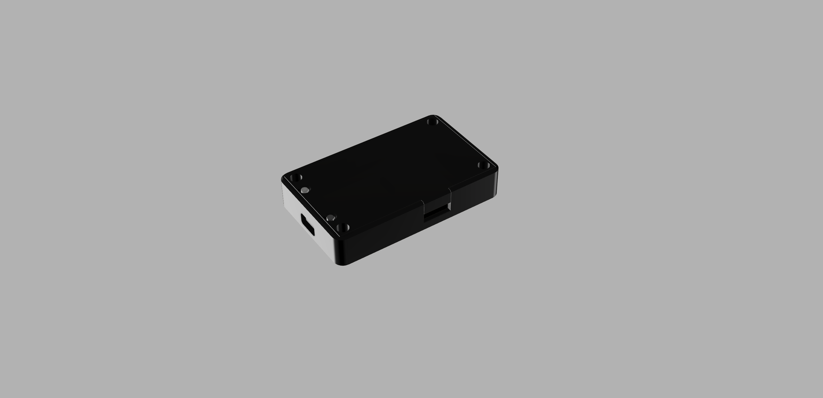
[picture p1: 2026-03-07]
case/back_render.png

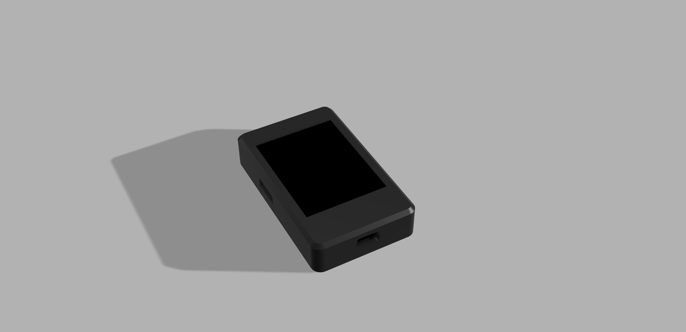
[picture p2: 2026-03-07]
case/front_render.png

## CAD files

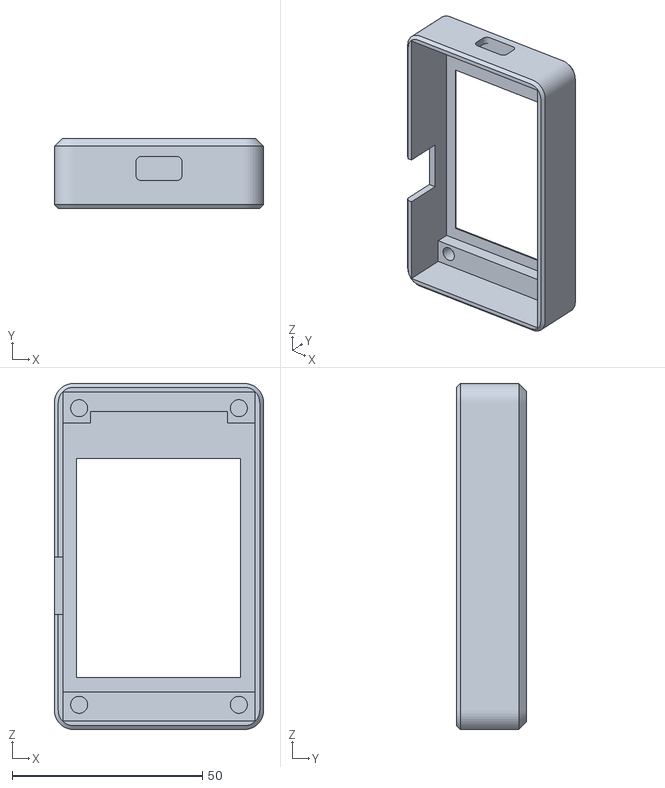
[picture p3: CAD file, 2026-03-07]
case/front.stl
55.0 x 18.4 x 91.0

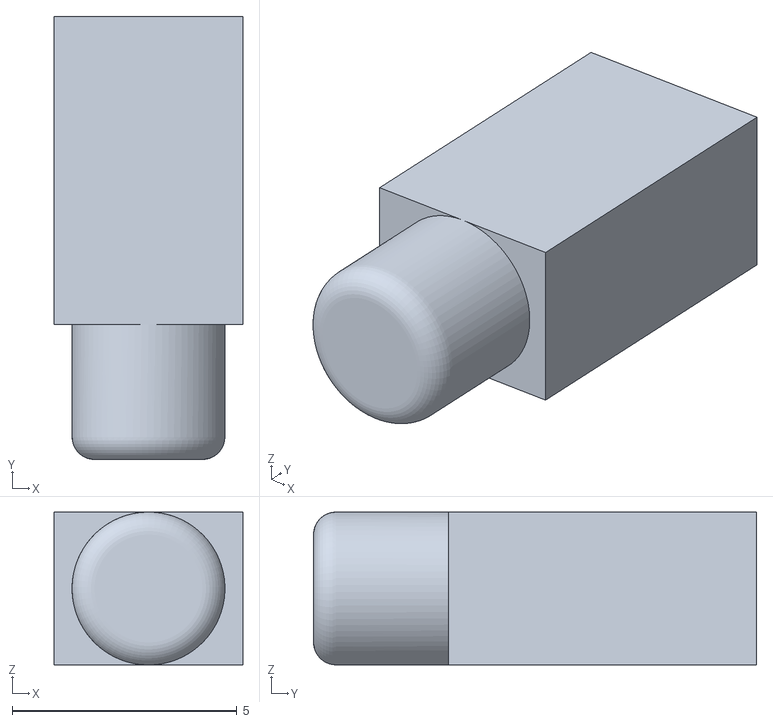
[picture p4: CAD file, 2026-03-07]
case/button.stl
4.20 x 9.85 x 3.40

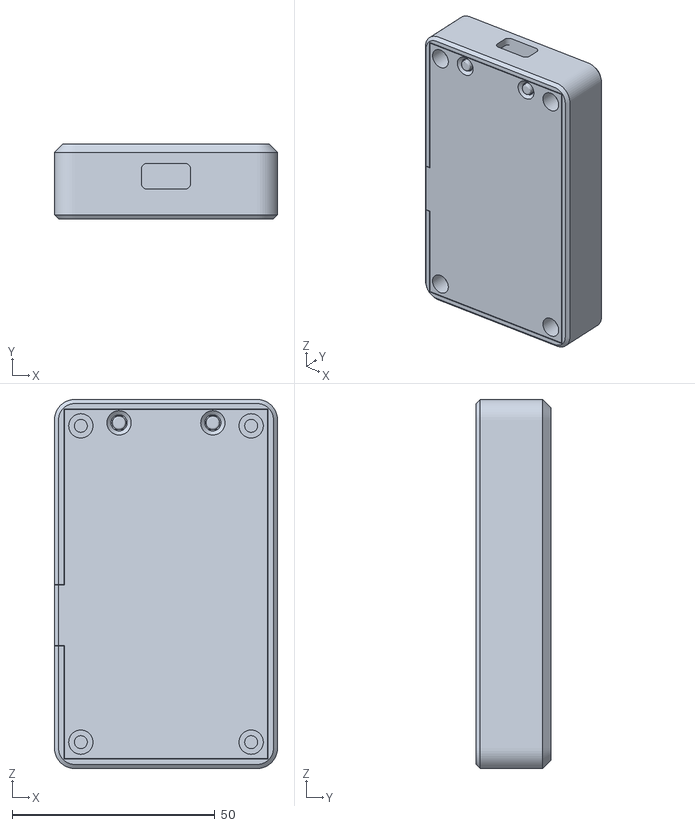
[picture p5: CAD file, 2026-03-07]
case/digital_photocard_IPS.stl
55.0 x 18.4 x 91.0

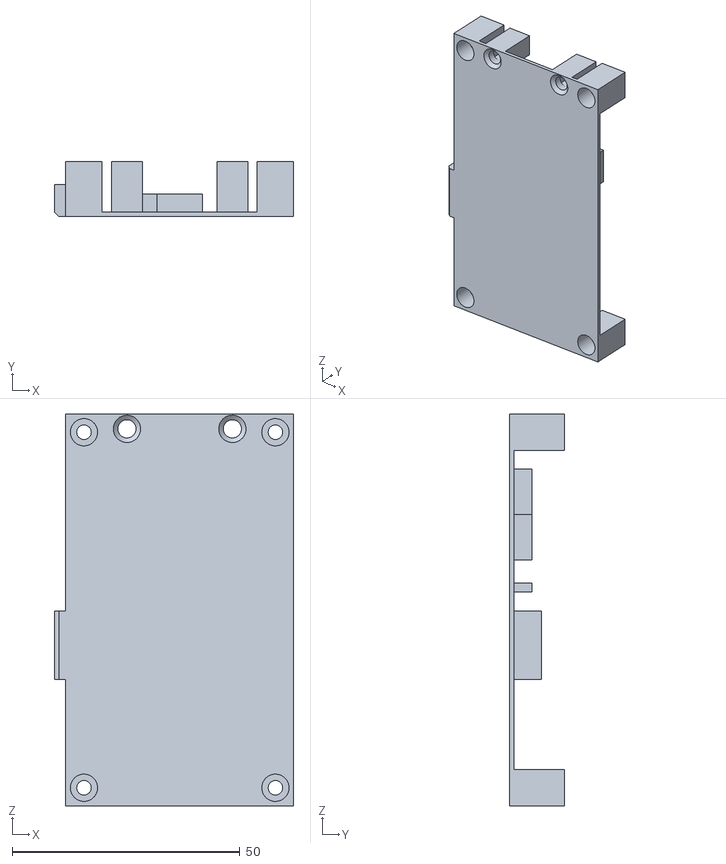
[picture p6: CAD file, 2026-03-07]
case/back.stl
52.5 x 12.1 x 86.0

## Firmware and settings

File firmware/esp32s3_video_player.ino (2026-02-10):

// ESP32-S3 2.8" Display Video Player (ES3C28P / ES3N28P)
// Optimized for speed using PSRAM and JPEGDEC
// Short press: next video | Long press: deep sleep

#include <FS.h>
#include <SD_MMC.h>
#include <vector>
#include <TFT_eSPI.h>
#include <TJpg_Decoder.h>
#include <esp_sleep.h>
#include <driver/gpio.h>
#include <esp_task_wdt.h>

using namespace fs;

// ============================================================================
// Pin Definitions
// ============================================================================
#define LCD_BL      45
#define SD_CLK      38
#define SD_CMD      40
#define SD_D0       39
#define SD_D1       41
#define SD_D2       48
#define SD_D3       47
#define BOOT_PIN    0

// Hardware pins
#define AUDIO_ENABLE_PIN  1  // Audio amp enable (LOW=enable, HIGH=disable)

// ============================================================================
// Configuration
// ============================================================================
#define BOOT_BUTTON_HOLD_TIME  1500
#define DEFAULT_FPS            15

// Use PSRAM for large buffers (ESP32-S3 has 8MB)
#define MJPEG_BUF_SIZE  (100 * 1024)  // 100KB for JPEG frame
#define READ_BUF_SIZE   (16 * 1024)   // 16KB read buffer

const char *MJPEG_FOLDER = "/mjpeg";

// ============================================================================
// Globals
// ============================================================================
std::vector<String> mjpegFileList;
int mjpegCount = 0;
int currentMjpegIndex = 0;

TFT_eSPI tft = TFT_eSPI();
File mjpegFile;

// Buffers in PSRAM
uint8_t *mjpegBuf = nullptr;
uint8_t *readBuf = nullptr;
int readBufPos = 0;
int readBufLen = 0;

unsigned long total_frames, start_ms;

volatile bool skipRequested = false;

void IRAM_ATTR onButtonPress() { skipRequested = true; }

// ============================================================================
// TJpg_Decoder callback
// ============================================================================
bool tftOutput(int16_t x, int16_t y, uint16_t w, uint16_t h, uint16_t* bitmap) {
    if (y >= tft.height()) return 0;
    tft.pushImage(x, y, w, h, bitmap);
    return 1;
}

// ============================================================================
// Fast buffered reading
// ============================================================================
inline int fastRead() {
    if (readBufPos >= readBufLen) {
        readBufLen = mjpegFile.read(readBuf, READ_BUF_SIZE);
        readBufPos = 0;
        if (readBufLen <= 0) return -1;
    }
    return readBuf[readBufPos++];
}

// Read entire JPEG frame into buffer
int readJpegFrame(uint8_t *buf, int maxSize) {
    int b, state = 0;

    // Find FFD8
    while ((b = fastRead()) >= 0) {
        if (state == 0 && b == 0xFF) state = 1;
        else if (state == 1 && b == 0xD8) break;
        else state = 0;
    }
    if (b < 0) return 0;

    buf[0] = 0xFF;
    buf[1] = 0xD8;
    int pos = 2;
    state = 0;

    while ((b = fastRead()) >= 0 && pos < maxSize - 1) {
        buf[pos++] = b;
        if (state == 0 && b == 0xFF) state = 1;
        else if (state == 1 && b == 0xD9) return pos;
        else state = 0;
    }
    return 0;
}

// ============================================================================
// Helpers
// ============================================================================
bool checkButtonHold() {
    if (digitalRead(BOOT_PIN) == LOW) {
        unsigned long start = millis();
        while (digitalRead(BOOT_PIN) == LOW) {
            if (millis() - start >= BOOT_BUTTON_HOLD_TIME) return true;
            delay(10);
        }
    }
    return false;
}

// Prepare all peripherals for minimum power consumption
void prepareForSleep() {
    Serial.println("Preparing for deep sleep...");
    Serial.flush();

    // Turn off display backlight
    digitalWrite(LCD_BL, LOW);

    // Put ILI9341 display in sleep mode
    tft.writecommand(0x10);  // Sleep in command
    delay(120);              // Required delay per datasheet

    // Disable audio amplifier (HIGH = disabled on this board)
    pinMode(AUDIO_ENABLE_PIN, OUTPUT);
    digitalWrite(AUDIO_ENABLE_PIN, HIGH);

    // Set unused expansion pins to input with no pull (reduce leakage)
    pinMode(2, INPUT);
    pinMode(3, INPUT);
    pinMode(14, INPUT);
    pinMode(21, INPUT);

    // Hold GPIO states during sleep
    gpio_hold_en(GPIO_NUM_45);   // Backlight off
    gpio_hold_en(GPIO_NUM_1);    // Audio disabled
}

// Deep sleep - wake on button press
void enterDeepSleep() {
    Serial.println("Entering deep sleep...");

    // Wait for button release first
    while (digitalRead(BOOT_PIN) == LOW) delay(10);
    delay(100);

    prepareForSleep();

    // Configure wake-up: button press only
    esp_sleep_enable_ext0_wakeup(GPIO_NUM_0, 0);  // Wake on LOW

    esp_deep_sleep_start();
}

int parseFps(const String &name) {
    int idx = name.lastIndexOf("fps");
    if (idx > 0) {
        int start = idx - 1;
        while (start > 0 && isDigit(name.charAt(start - 1))) start--;
        int fps = name.substring(start, idx).toInt();
        if (fps > 0 && fps <= 60) return fps;
    }
    return DEFAULT_FPS;
}

// ============================================================================
// Video playback
// ============================================================================
void loadFileList() {
    File dir = SD_MMC.open(MJPEG_FOLDER);
    if (!dir) {
        tft.setTextColor(TFT_RED); tft.setTextSize(2);
        tft.setCursor(20, 140); tft.print("No /mjpeg folder!");
        while (1) delay(1000);
    }
    mjpegFileList.clear();
    while (File f = dir.openNextFile()) {
        String name = f.name();
        if (!f.isDirectory() && name.endsWith(".mjpeg")) {
            mjpegFileList.push_back(name);
        }
        f.close();
    }
    dir.close();
    mjpegCount = mjpegFileList.size();
    Serial.printf("Found %d videos\n", mjpegCount);
}

void playVideo(int idx) {
    String path = String(MJPEG_FOLDER) + "/" + mjpegFileList[idx];
    int fps = parseFps(mjpegFileList[idx]);
    unsigned long frameMicros = 1000000UL / fps;

    Serial.printf("Play: %s @ %d fps (%lu us/frame)\n", path.c_str(), fps, frameMicros);

    mjpegFile = SD_MMC.open(path.c_str(), "r");
    if (!mjpegFile) return;

    readBufPos = readBufLen = 0;
    tft.fillScreen(TFT_BLACK);
    start_ms = millis();
    total_frames = 0;

    unsigned long nextFrameTime = micros();
    unsigned long skippedFrames = 0;

    while (!skipRequested) {
        unsigned long now = micros();

        // Read next frame
        int size = readJpegFrame(mjpegBuf, MJPEG_BUF_SIZE);
        if (size == 0) break;

        // Frame skip logic: if we're behind by more than 1 frame, skip display
        if (now > nextFrameTime + frameMicros) {
            skippedFrames++;
            nextFrameTime += frameMicros;
            continue;
        }

        // Decode and display frame
        TJpgDec.drawJpg(0, 0, mjpegBuf, size);
        total_frames++;

        // Feed watchdog after each successful frame
        esp_task_wdt_reset();

        // Precise frame pacing using microseconds
        nextFrameTime += frameMicros;
        now = micros();
        if (nextFrameTime > now) {
            delayMicroseconds(nextFrameTime - now);
        }

        // Check for button press
        if (digitalRead(BOOT_PIN) == LOW) {
            unsigned long holdStart = millis();
            while (digitalRead(BOOT_PIN) == LOW) {
                if (millis() - holdStart >= BOOT_BUTTON_HOLD_TIME) {
                    // Long press - go to sleep
                    mjpegFile.close();
                    Serial.printf("Done: %lu frames, %lu skipped, %.1f fps\n",
                                  total_frames, skippedFrames,
                                  1000.0 * total_frames / (millis() - start_ms));
                    enterDeepSleep();
                    return;
                }
                delay(10);
            }
            // Short press - skip to next video
            skipRequested = true;
        }
    }

    skipRequested = false;

    Serial.printf("Done: %lu frames, %lu skipped, %.1f fps\n",
                  total_frames, skippedFrames,
                  1000.0 * total_frames / (millis() - start_ms));
    mjpegFile.close();
}

// ============================================================================
// Setup
// ============================================================================
void setup() {
    Serial.begin(115200);
    delay(500);
    Serial.println("\n=== ESP32-S3 Video Player ===");

    // Check wake-up reason and release GPIO holds from previous sleep
    esp_sleep_wakeup_cause_t wakeup_reason = esp_sleep_get_wakeup_cause();
    gpio_hold_dis(GPIO_NUM_45);  // Backlight
    gpio_hold_dis(GPIO_NUM_1);   // Audio enable

    if (wakeup_reason == ESP_SLEEP_WAKEUP_EXT0) {
        Serial.println("Woke from deep sleep (button)");
    }

    // Check PSRAM
    if (psramFound()) {
        Serial.printf("PSRAM: %d bytes\n", ESP.getPsramSize());
    } else {
        Serial.println("Warning: No PSRAM found!");
    }

    pinMode(LCD_BL, OUTPUT);
    digitalWrite(LCD_BL, HIGH);

    // Display
    tft.init();
    tft.setRotation(0);
    tft.setSwapBytes(true);
    tft.fillScreen(TFT_BLACK);
    Serial.printf("Display: %dx%d\n", tft.width(), tft.height());

    // TJpg_Decoder setup
    TJpgDec.setJpgScale(1);
    TJpgDec.setCallback(tftOutput);

    // Allocate buffers in PSRAM
    mjpegBuf = (uint8_t *)ps_malloc(MJPEG_BUF_SIZE);
    readBuf = (uint8_t *)ps_malloc(READ_BUF_SIZE);
    if (!mjpegBuf || !readBuf) {
        Serial.println("PSRAM alloc failed, using heap");
        if (!mjpegBuf) mjpegBuf = (uint8_t *)malloc(MJPEG_BUF_SIZE);
        if (!readBuf) readBuf = (uint8_t *)malloc(READ_BUF_SIZE);
    }
    if (!mjpegBuf || !readBuf) {
        tft.setTextColor(TFT_RED);
        tft.setCursor(20, 140);
        tft.print("Memory error!");
        while (1) delay(1000);
    }

    // SD Card - SDIO 4-bit mode at 80MHz
    SD_MMC.setPins(SD_CLK, SD_CMD, SD_D0, SD_D1, SD_D2, SD_D3);
    if (!SD_MMC.begin("/sdcard", true, false, 80000)) {
        if (!SD_MMC.begin("/sdcard", false)) {
            tft.setTextColor(TFT_RED);
            tft.setCursor(20, 140);
            tft.print("SD Error!");
            while (1) delay(1000);
        }
    }
    Serial.printf("SD: %lluMB\n", SD_MMC.cardSize() / (1024 * 1024));

    loadFileList();

    pinMode(BOOT_PIN, INPUT);
    attachInterrupt(digitalPinToInterrupt(BOOT_PIN), onButtonPress, FALLING);

    // Task watchdog: auto-reset if SD card or other operation hangs for 10s
    esp_task_wdt_config_t wdt_config = {
        .timeout_ms = 10000,
        .idle_core_mask = 0,
        .trigger_panic = true
    };
    esp_task_wdt_reconfigure(&wdt_config);
    esp_task_wdt_add(NULL);

    Serial.println("Ready!");
}

// ============================================================================
// Loop
// ============================================================================
void loop() {
    if (mjpegCount > 0) {
        playVideo(currentMjpegIndex);
        currentMjpegIndex = (currentMjpegIndex + 1) % mjpegCount;
    } else {
        tft.fillScreen(TFT_BLACK);
        tft.setTextColor(TFT_YELLOW);
        tft.setCursor(20, 140);
        tft.print("No videos");
        delay(2000);
    }
}

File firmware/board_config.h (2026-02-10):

/*******************************************************************************
 * Board Configuration Header
 *
 * Supports multiple ESP32 display boards:
 * - ESP32-2432S028 (CYD - Cheap Yellow Display)
 * - ES3C28P / ES3N28P (2.8" ESP32-S3 Display from LCDWiki)
 ******************************************************************************/
#ifndef _BOARD_CONFIG_H_
#define _BOARD_CONFIG_H_

// Uncomment ONE of the following board definitions:
// #define BOARD_CYD_2432S028      // Original Cheap Yellow Display (ESP32)
#define BOARD_ESP32S3_ES3C28P   // 2.8" ESP32-S3 Display (LCDWiki)

/*******************************************************************************
 * ESP32-2432S028 (CYD - Cheap Yellow Display)
 * Uses standard ESP32 with SPI SD card
 ******************************************************************************/
#if defined(BOARD_CYD_2432S028)

// Display pins (SPI)
#define LCD_CS      15
#define LCD_DC      2
#define LCD_SCK     14
#define LCD_MOSI    13
#define LCD_MISO    12
#define LCD_BL      21      // Backlight (some models use 27)

// SD Card pins (SPI - VSPI)
#define SD_CS       5
#define SD_MISO     19
#define SD_MOSI     23
#define SD_SCK      18
#define SD_USE_SPI  1       // Use SPI mode for SD card

// I2C pins (shared with SD - only use when SD not in use)
#define I2C_SDA     19
#define I2C_SCL     27
#define I2C_DEDICATED 0     // I2C shares pins with SD, need mode switching

// Touch screen (XPT2046 resistive - SPI)
#define TOUCH_CS    33
#define TOUCH_IRQ   36
#define TOUCH_TYPE  "XPT2046"

// Boot button
#define BOOT_PIN    0

// No audio on standard CYD
#define HAS_AUDIO   0

// No RGB LED on standard CYD
#define HAS_RGB_LED 0

// Board identification
#define BOARD_NAME  "ESP32-2432S028 (CYD)"

/*******************************************************************************
 * ES3C28P / ES3N28P - 2.8" ESP32-S3 Display (LCDWiki)
 * Uses ESP32-S3 with SDIO SD card and capacitive touch
 ******************************************************************************/
#elif defined(BOARD_ESP32S3_ES3C28P)

// Display pins (SPI)
#define LCD_CS      10
#define LCD_DC      46
#define LCD_SCK     12
#define LCD_MOSI    11
#define LCD_MISO    13
#define LCD_BL      45      // Backlight (HIGH = on, LOW = off)

// SD Card pins (SDIO 4-bit mode)
#define SD_CLK      38
#define SD_CMD      40
#define SD_D0       39
#define SD_D1       41
#define SD_D2       48
#define SD_D3       47
#define SD_USE_SPI  0       // Use SDIO mode (not SPI)

// I2C pins (shared with capacitive touch - can use simultaneously with SD!)
#define I2C_SDA     16
#define I2C_SCL     15
#define I2C_DEDICATED 1     // I2C is on dedicated pins, no conflict with SD

// Touch screen (FT6336 capacitive - I2C)
#define TOUCH_RST   18
#define TOUCH_IRQ   17
#define TOUCH_TYPE  "FT6336"
#define FT6336_ADDR 0x38    // I2C address

// Audio (I2S with ES8311 codec)
#define HAS_AUDIO   1
#define AUDIO_EN    1       // Enable pin (LOW = enable)
#define AUDIO_MCLK  4       // Master clock
#define AUDIO_BCLK  5       // Bit clock
#define AUDIO_DOUT  6       // Data out
#define AUDIO_WS    7       // Word select (LRCLK)
#define AUDIO_DIN   8       // Data in (mic)

// RGB LED (WS2812-style, single wire)
#define HAS_RGB_LED 1
#define RGB_LED_PIN 42

// Boot button
#define BOOT_PIN    0

// Battery voltage sensing
#define BATT_ADC    9

// Expansion pins (general purpose)
#define EXPAND_IO1  2
#define EXPAND_IO2  3
#define EXPAND_IO3  14
#define EXPAND_IO4  21

// UART0 (main serial)
#define UART_RX     43
#define UART_TX     44

// Board identification
#define BOARD_NAME  "ES3C28P (ESP32-S3 2.8\" Display)"

#else
#error "Please define a board type in board_config.h"
#endif

/*******************************************************************************
 * Common settings
 ******************************************************************************/

// Display settings
#define DISPLAY_WIDTH   240
#define DISPLAY_HEIGHT  320
#define DISPLAY_DRIVER  "ILI9341"

// SPI speeds
#define DISPLAY_SPI_SPEED   40000000L   // 40MHz for display
#define SD_SPI_SPEED        80000000L   // 80MHz for SD (SPI mode only)

// Button debounce
#define BOOT_BUTTON_DEBOUNCE_TIME   400     // ms for short press
#define BOOT_BUTTON_HOLD_TIME       1500    // ms for long press

// Video playback
#define DEFAULT_FPS         15
#define MAX_FILES           50
#define MJPEG_FOLDER        "/mjpeg"

#endif // _BOARD_CONFIG_H_

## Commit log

2026-02-10 Organize project as monorepo with firmware, collection app, and case
    Consolidate esp32s3_video_player and digital-photocard-collection into a
    single repo with clearer folder names: firmware/, collection-app/, case/,
    and docs/. Add top-level README and .gitignore.
2026-02-10 Remove CO2 sensor code from firmware, simplify to video-only player
    Strip out SCD41 sensor, RGB LED alerts, battery monitoring, and sensor
    mode. Firmware now only plays videos: short press skips, long press sleeps.
    [esp32s3_video_player.ino]
2026-03-07 Update docs, add case STLs, migrate collection app to uv
    - Rewrite README with full hardware list, setup guide, and usage instructions
    - Credit esp32-2432S028_video_player as firmware starting point
    - Add case assembly instructions and STL files (front, back, button)
    - Migrate collection app from pip/requirements.txt to uv/pyproject.toml
    - Update collection app components and database service
    [back.stl, button.stl, digital_photocard_IPS.stl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]
